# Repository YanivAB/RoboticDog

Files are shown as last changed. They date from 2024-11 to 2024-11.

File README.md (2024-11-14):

# Robotic Dog Project
This repository contains the code and resources for our final engineering project: a robotic dog designed and built as part of our Mechanical Engineering and Robotics studies at the Technion. The project integrates biomechanical principles to develop a four-legged robotic prototype that mimics the movements of a real dog.

# Project Overview
## Objective
The primary goal is to design and construct a robotic dog prototype capable of walking independently and transitioning between positions (stand, sit, and lie down). The project integrates:
Mechanical design and kinematics
Mechatronics and software development
Biomechanical concepts for robotic motion

## Key Features
Self-Stabilizing Movement: Robot walks and maintains balance on uneven terrain.
Pose Transitions: Switches between standing, sitting, and lying down positions.
Servo Motor System: Driven by SPT5425LV-W and MG996R servos, enabling precise control of leg joints.
Inverse Kinematics & Trajectory Planning: Ensures smooth movement through calculated joint angles.
Communication: Coordination between Raspberry Pi and Teensy microcontroller for motor control and trajectory planning.

# Hardware Components
Motors: SPT5425LV-W (25 kg/cm torque), MG996R (10 kg/cm torque)
Controller: Teensy microcontroller for PWM motor control
Processor: Raspberry Pi for kinematics calculations and trajectory planning
Structure: 3D-printed parts (PLA) for lightweight and robust assembly

# Software Architecture
Inverse Kinematics: IK(x, y) - Computes joint angles based on desired foot coordinates.
Trajectory Planning: trajectory_plan(x0, y0, R, steps) - Generates smooth movement paths for each leg.
Motor Control: send_angles(angles, pose_name) - Sends angle commands to each servo motor.

# Setup and Installation
## Prerequisites
Hardware: Raspberry Pi, Teensy, servo motors (SPT5425LV-W and MG996R)
Software: Python, Arduino IDE with required libraries for motor control (or custom PWM control)
Installation
Clone this repository:
bash
Copy code
git clone [https://github.com/username/robotic-dog-project.git]
cd robotic-dog-project
Load and compile the Teensy control code using the Arduino IDE.
Run the main Python scripts on the Raspberry Pi to initiate kinematics and control loops.

# Challenges and Solutions
Servo Durability: Reinforced motor gears with Teflon layers to improve durability under load.
Weight Distribution: Adjusted battery and motor placement for optimal balance.
Custom Movement Control: Developed custom code for efficient motor control and reduced reliance on pre-built libraries.

# Future Enhancements
Advanced Mobility: Additional gaits and obstacle avoidance
Remote Control via ROS: Integration with ROS for wireless operation
AI Capabilities: Vision processing and autonomous navigation

## Technion- Israel Institute of Technology

# Contributors
Natay Baruchis - https://www.linkedin.com/in/nitai-bruchis/
Yaniv Abramov - https://www.linkedin.com/in/yaniv-abramov/
Supervised by: Roman Shamsutdinov

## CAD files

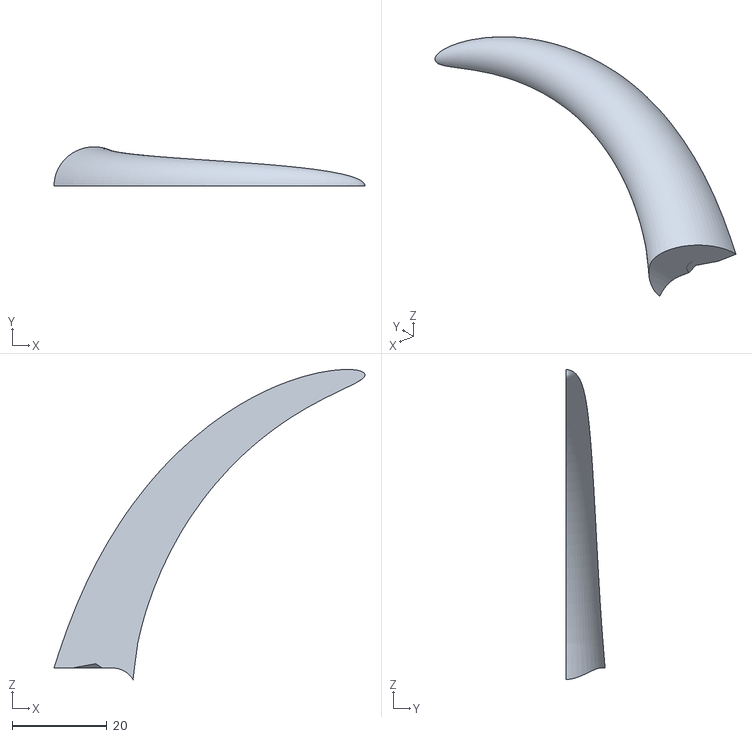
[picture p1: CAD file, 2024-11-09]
CAD_models/tail right.STL
65.7 x 8.30 x 65.5

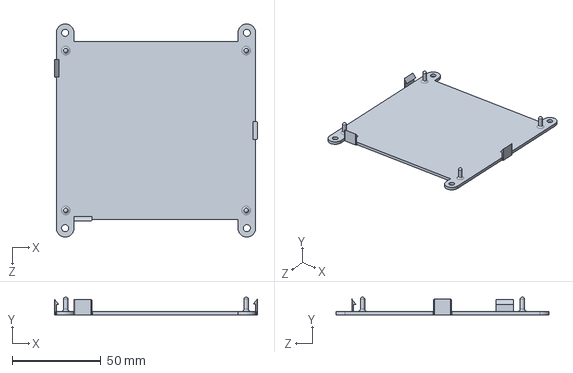
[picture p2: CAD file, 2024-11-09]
CAD_models/card caseing.SLDPRT
114.3 x 10.0 x 120.0 mm

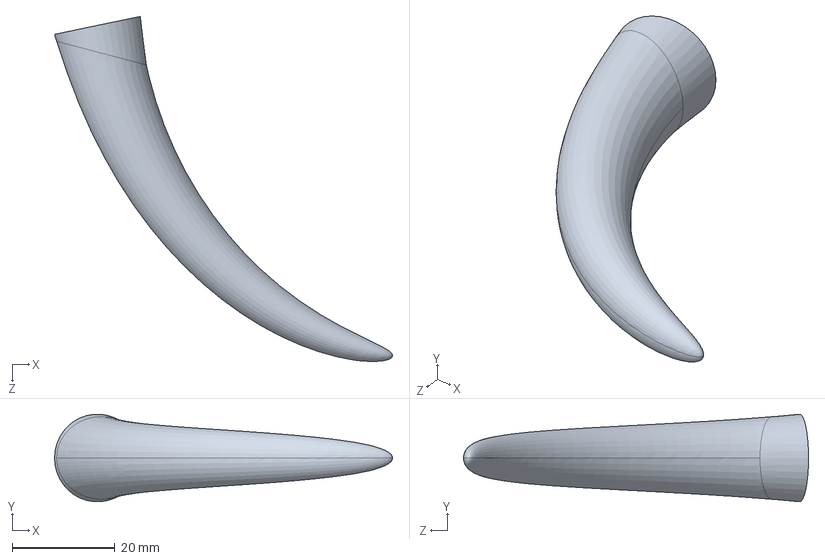
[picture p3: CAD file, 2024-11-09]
CAD_models/robot tail.SLDPRT
65.9 x 17.0 x 67.3 mm

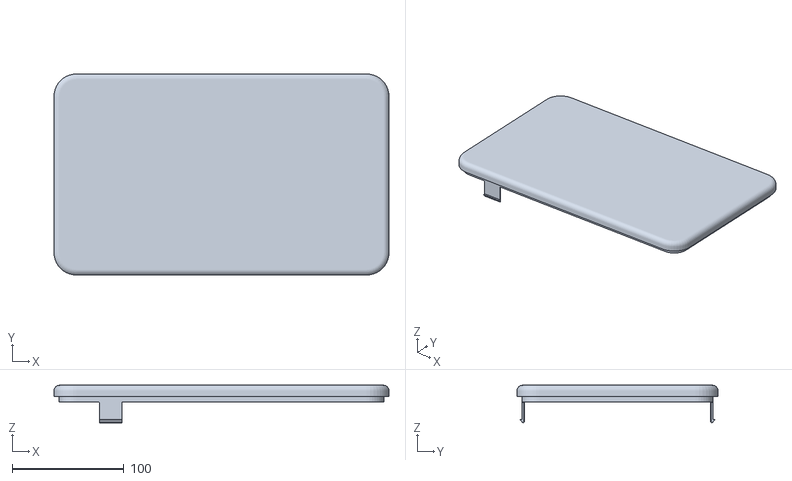
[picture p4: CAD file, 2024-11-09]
CAD_models/robot lid.STL
300.0 x 180.0 x 33.6

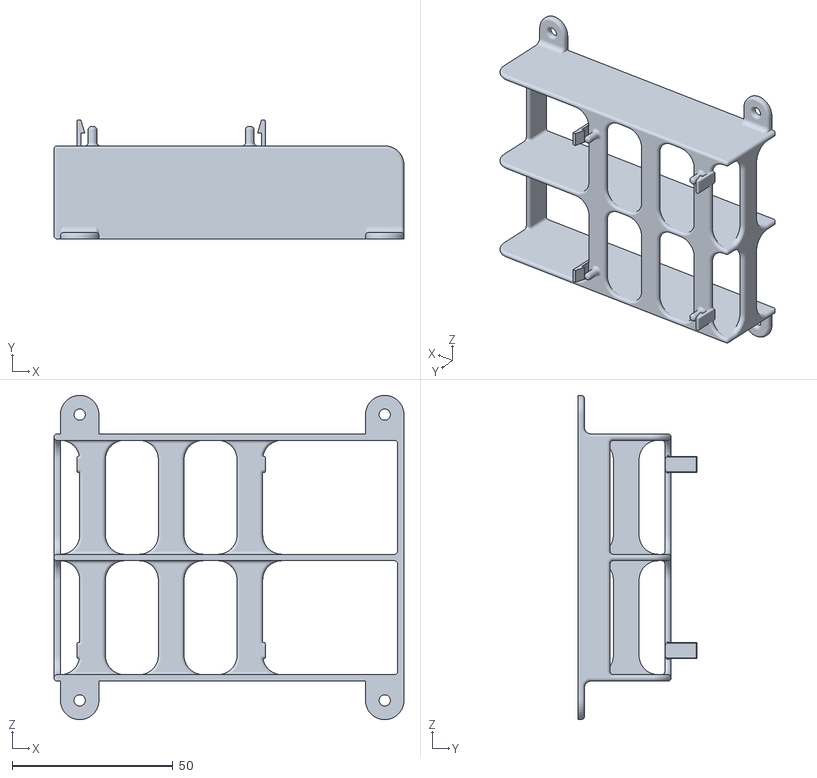
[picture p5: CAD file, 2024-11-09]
CAD_models/battery_casing2.STL
109.0 x 37.0 x 101.0

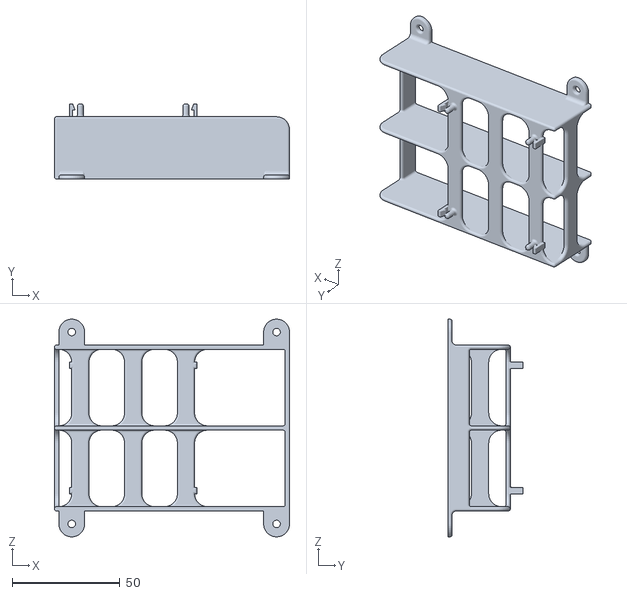
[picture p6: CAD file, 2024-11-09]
CAD_models/battery_casing1.STL
109.0 x 35.0 x 101.0

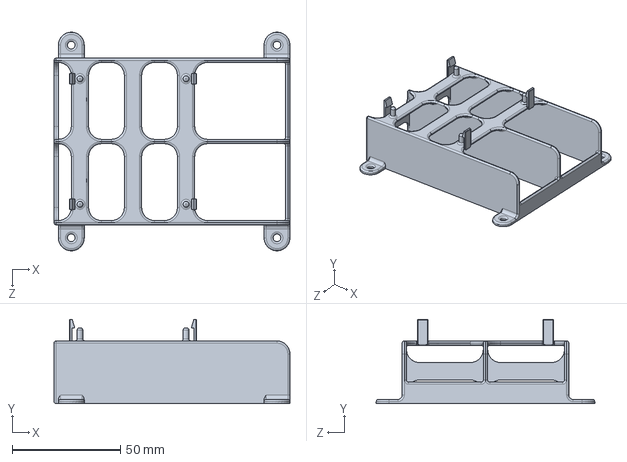
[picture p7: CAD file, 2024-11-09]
CAD_models/battery_casing.SLDPRT
109.0 x 39.0 x 101.0 mm

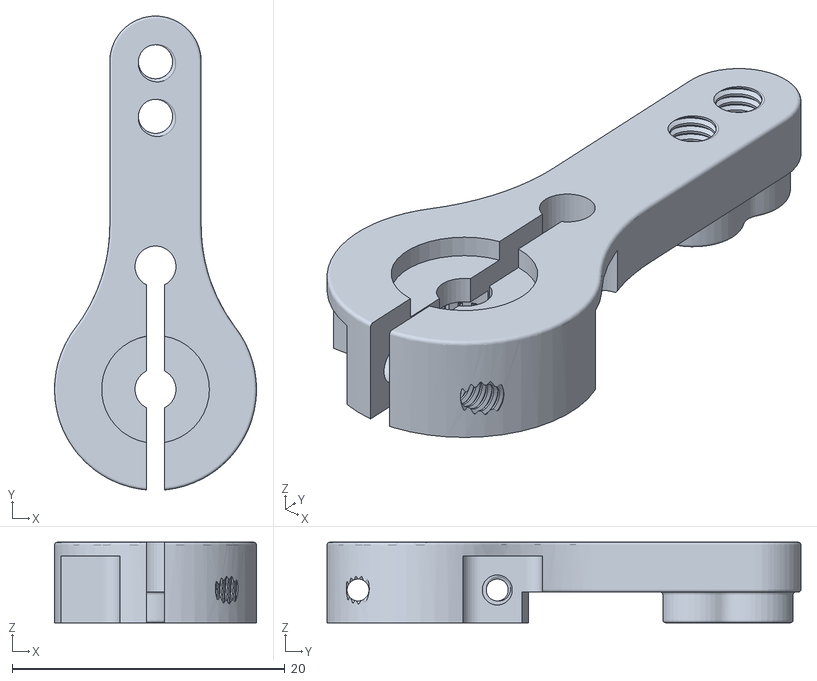
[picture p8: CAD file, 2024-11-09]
CAD_models/SERVO ARM HORN 25T ALUMINIUM.STL
14.8 x 34.7 x 5.90

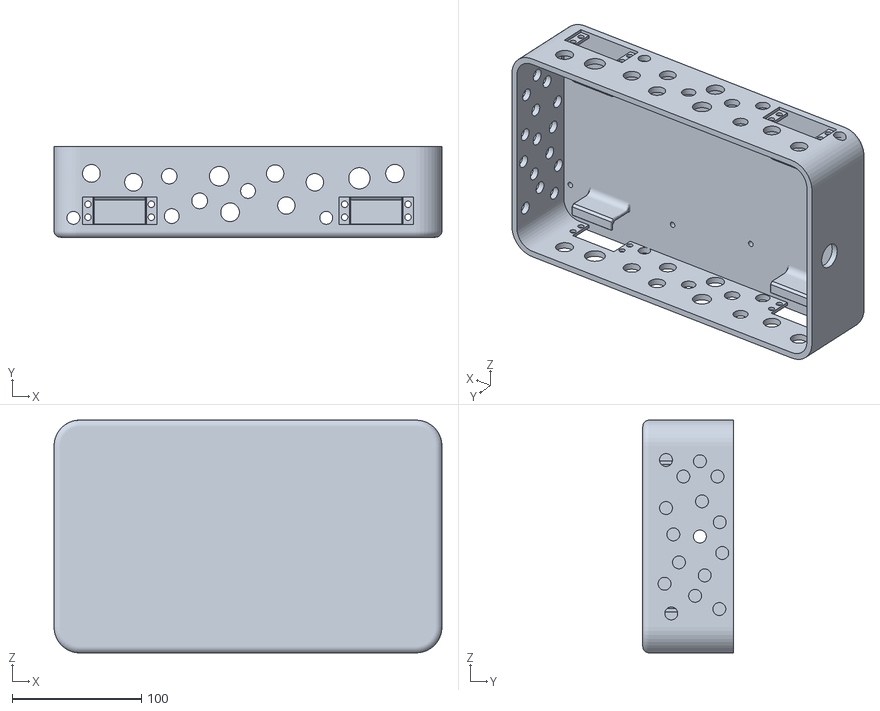
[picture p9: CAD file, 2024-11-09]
CAD_models/Torso_1.STL
300.0 x 70.0 x 180.0

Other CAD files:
CAD_models/tail left.STL
CAD_models/battery_casing.STL
CAD_models/card caseing.STL

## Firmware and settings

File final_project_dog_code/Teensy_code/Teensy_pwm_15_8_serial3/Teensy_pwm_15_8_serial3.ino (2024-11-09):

#include <Arduino.h>

#define ARM_MATH_CM4
#include <arm_math.h>
#define HWSERIAL Serial3  // UART

#define PWM_RSF 2  // PWM shoulder right front
#define PWM_REF 3  // PWM elbow right front
#define PWM_RSB 4  // PWM shoulder right back
#define PWM_REB 5  // PWM elbow right back
#define PWM_LSF 6  // PWM shoulder left front
#define PWM_LEF 7  // PWM elbow left front
#define PWM_LSB 8  // PWM shoulder left back
#define PWM_LEB 9  // PWM elbow left back

char greeting = 1;  // The program welcomes
char control = 0;   // 1 begin control loop

const int down[8] = {10 /*RSF*/, 70, 10, 70, 165 /*LSF*/, 170, 165, 170};


/*
int p1 = 1600, new_angle1 = 0, old_angle1 = 0, e1 = 0;
int p2 = 1600, new_angle2 = 0, old_angle2 = 0, e2 = 0;
int p3 = 1600, new_angle3 = 0, old_angle3 = 0, e3 = 0;
int p4 = 1600, new_angle4 = 0, old_angle4 = 0, e4 = 0;
int p5 = 1600, new_angle5 = 0, old_angle5 = 0, e5 = 0;
int p6 = 1600, new_angle6 = 0, old_angle6 = 0, e6 = 0;
int p7 = 1600, new_angle7 = 0, old_angle7 = 0, e7 = 0;
int p8 = 1600, new_angle8 = 0, old_angle8 = 0, e8 = 0;
*/

//down
int p1 = 1970, new_angle1 = 0, old_angle1 = 10, e1 = 0;
int p2 = 4190, new_angle2 = 0, old_angle2 = 70, e2 = 0;
int p3 = 1970, new_angle3 = 0, old_angle3 = 10, e3 = 0;
int p4 = 4190, new_angle4 = 0, old_angle4 = 70, e4 = 0;
int p5 = 7705, new_angle5 = 0, old_angle5 = 165, e5 = 0;
int p6 = 7830, new_angle6 = 0, old_angle6 = 145, e6 = 0;
int p7 = 7705, new_angle7 = 0, old_angle7 = 165, e7 = 0;
int p8 = 7830, new_angle8 = 0, old_angle8 = 180, e8 = 0;


int pmin = 1600;
int pmax = 8200;

/*   UART setup              */
unsigned char bytecount = 0;
unsigned char received_data[0x08] = { 0 };
unsigned char p = 0;
unsigned char i = 0;


volatile bool ledState = false;  // from ChatGPT

void setup() {
  // from ChatGPT begin
  pinMode(LED_BUILTIN, OUTPUT);

  // Stop the timers before configuration
  PIT_MCR = 0x00;  // Enable PIT and disable freezing in the debugger

  // PIT0 configuration
  PIT_LDVAL0 = 200000 - 1;  // Set timer period (1 second at 120 MHz)
  PIT_TCTRL0 = 0x3;         // Enable timer and interrupt

  // Assign interrupt function
  attachInterruptVector(IRQ_PIT, pit0_isr);
  NVIC_ENABLE_IRQ(IRQ_PIT);
  // end ChatGPT


// UART
Serial3.begin(115200);
Serial.begin(115200);

// PWM Setup
analogWriteResolution(16);  // analogWrite value 0 to 4095, or 4096 for high
// analogWriteResolution(10);  // analogWrite value 0 to 1023, or 1023 for high

// sample  analogWriteFrequency(2, 10000);   // PWM frequency 10kHZ
analogWriteFrequency(2, 50);  // PWM frequency 50 HZ
analogWriteFrequency(3, 50);  // PWM frequency 50 HZ
analogWriteFrequency(4, 50);  // PWM frequency 50 HZ
analogWriteFrequency(5, 50);  // PWM frequency 50 HZ
analogWriteFrequency(6, 50);  // PWM frequency 50 HZ
analogWriteFrequency(7, 50);  // PWM frequency 50 HZ
analogWriteFrequency(8, 50);  // PWM frequency 50 HZ
analogWriteFrequency(9, 50);  // PWM frequency 50 HZ

/* PinMode setup */

  pinMode(PWM_RSF, OUTPUT);
  pinMode(PWM_REF, OUTPUT);
  pinMode(PWM_RSB, OUTPUT);
  pinMode(PWM_REB, OUTPUT);
  pinMode(PWM_LSF, OUTPUT);
  pinMode(PWM_LEF, OUTPUT);
  pinMode(PWM_LSB, OUTPUT);
  pinMode(PWM_LEB, OUTPUT);


// test
//  analogWrite(PWM_RSF, 3300); = 1.007ms
// analogWrite(PWM_RSF, 2950);  // 900ms
// analogWrite(PWM_REB, 6900);  // 2100ms
//  analogWrite(PWM_RSF, 1600); //8200
//  analogWrite(PWM_REF, 4950);
//  analogWrite(PWM_RSB, 6050);
//  analogWrite(PWM_REB, 6900);  // 2100ms

}

void loop() 
{
  // Main loop is empty, all work is done in the interrupt
// The program welcomes
if (greeting == 1) {
  Serial.println("Teensy 4.0 RS motors control v000 ");
  


analogWrite(PWM_RSF, p1);
analogWrite(PWM_REF, p2);
analogWrite(PWM_RSB, p3);
analogWrite(PWM_REB, p4);


analogWrite(PWM_LSF, p5);
analogWrite(PWM_LEF, p6);
analogWrite(PWM_LSB, p7);
analogWrite(PWM_LEB, p8);    

  greeting = 0;
}

/* read data from UART */
while (Serial3.available() && bytecount < 0x08) {
  received_data[bytecount] = Serial3.read();
  Serial.println(received_data[bytecount], HEX);
  bytecount++;
}

if (bytecount == 0x08) {

  new_angle1 = received_data[0x00];
  new_angle2 = received_data[0x01];
  new_angle3 = received_data[0x02];
  new_angle4 = received_data[0x03];
  new_angle5 = received_data[0x04];
  new_angle6 = received_data[0x05];
  new_angle7 = received_data[0x06];
  new_angle8 = received_data[0x07];

/*
  pnew1 = pmin + (received_data[0x00] * 37);
  pnew2 = pmin + (received_data[0x01] * 37);
  pnew3 = pmin + (received_data[0x02] * 37);
  pnew4 = pmin + (received_data[0x04] * 37);
  pnew6 = pmin + (received_data[0x05] * 37);
  pnew7 = pmin + (received_data[0x06] * 37);
  pnew8 = pmin + (received_data[0x07] * 37);
*/
  p = 1;
  bytecount = 0;
  control = 1;
}

if (p == 1) {
  for (i = 0; i < 0x08; i++) {
    //Serial.println(received_data[i], HEX);  // number, base 16/hexadecimal
    //Serial.println(p1, DEC);                // number, base 16/hexadecimal
  }

  // Serial1.print("M_En = ");
  // Serial.println(motors, DEC);  // number, base 16/hexadecimal
  p = 0;
}
}



void pit0_isr() 
{
    if (PIT_TFLG0 & 1)   // Check the interrupt flag for PIT0
    {  

      if(control == 1) 
      {
// Control loop for RC motor 1
if (old_angle1 != new_angle1) {
  e1 = old_angle1 - new_angle1;
  if (e1 < 0) {
    old_angle1 = old_angle1 + 1;
  } else {
    old_angle1 = old_angle1 - 1;
  }
  p1 = pmin + (old_angle1 * 37);
  analogWrite(PWM_RSF, p1);
} else {
  old_angle1 = new_angle1;
}

// Control loop for RC motor 2
if (old_angle2 != new_angle2) {
  e2 = old_angle2 - new_angle2;
  if (e2 < 0) {
    old_angle2 = old_angle2 + 1;
  } else {
    old_angle2 = old_angle2 - 1;
  }
  p2 = pmin + (old_angle2 * 37);
  analogWrite(PWM_REF, p2);
} else {
  old_angle2 = new_angle2;
}

// Control loop for RC motor 3
if (old_angle3 != new_angle3) {
  e3 = old_angle3 - new_angle3;
  if (e3 < 0) {
    old_angle3 = old_angle3 + 1;
  } else {
    old_angle3 = old_angle3 - 1;
  }
  p3 = pmin + (old_angle3 * 37);
  analogWrite(PWM_RSB, p3);
} else {
  old_angle3 = new_angle3;
}

// Control loop for RC motor 4
if (old_angle4 != new_angle4) {
  e4 = old_angle4 - new_angle4;
  if (e4 < 0) {
    old_angle4 = old_angle4 + 1;
  } else {
    old_angle4 = old_angle4 - 1;
  }
  p4 = pmin + (old_angle4 * 37);
  analogWrite(PWM_REB, p4);
} else {
  old_angle4 = new_angle4;
}

// Control loop for RC motor 5
if (old_angle5 != new_angle5) {
  e5 = old_angle5 - new_angle5;
  if (e5 < 0) {
    old_angle5 = old_angle5 + 1;
  } else {
    old_angle5 = old_angle5 - 1;
  }
  p5 = pmin + (old_angle5 * 37);
  analogWrite(PWM_LSF, p5);
} else {
  old_angle5 = new_angle5;
}

// Control loop for RC motor 6
if (old_angle6 != new_angle6) {
  e6 = old_angle6 - new_angle6;
  if (e6 < 0) {
    old_angle6 = old_angle6 + 1;
  } else {
    old_angle6 = old_angle6 - 1;
  }
  p6 = pmin + (old_angle6 * 37);
  analogWrite(PWM_LEF, p6);
} else {
  old_angle6 = new_angle6;
}

// Control loop for RC motor 7
if (old_angle7 != new_angle7) {
  e7 = old_angle7 - new_angle7;
  if (e7 < 0) {
    old_angle7 = old_angle7 + 1;
  } else {
    old_angle7 = old_angle7 - 1;
  }
  p7 = pmin + (old_angle7 * 37);
  analogWrite(PWM_LSB, p7);
} else {
  old_angle7 = new_angle7;
}

// Control loop for RC motor 8
if (old_angle8 != new_angle8) {
  e8 = old_angle8 - new_angle8;
  if (e8 < 0) {
    old_angle8 = old_angle8 + 1;
  } else {
    old_angle8 = old_angle8 - 1;
  }
  p8 = pmin + (old_angle8 * 37);
   analogWrite(PWM_LEB, p8);
} else {
  old_angle8 = new_angle8;
}

/*     
analogWrite(PWM_RSF, p1);
analogWrite(PWM_REF, p2);
analogWrite(PWM_RSB, p3);
analogWrite(PWM_REB, p4);
analogWrite(PWM_LSF, p5);
analogWrite(PWM_LEF, p6);
analogWrite(PWM_LSB, p7);
analogWrite(PWM_LEB, p8);
*/

    }

        PIT_TFLG0 = 1;         // Clear the interrupt flag
        ledState = !ledState;  // Toggle the LED state
        digitalWrite(LED_BUILTIN, ledState);
    }
}

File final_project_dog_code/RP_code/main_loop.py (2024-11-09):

import math
import serial
import time
import RPi.GPIO as GPIO
import pickle
import os

from IK_func_8 import IK, RSF , RSB , REF , REB , LSF , LEB , LEF , LEB , theta2servo , trajectory_plan , traj_use , turn_angles

def ledon(ledpin):
    GPIO.setmode(GPIO.BCM)
    GPIO.setup(ledpin , GPIO.OUT)
    GPIO.output(ledpin , GPIO.HIGH)
    time.sleep(2)
    GPIO.output(ledpin , GPIO.LOW)
print('initializing')
# Setup serial communication and transmission function
ser = serial.Serial('/dev/ttyAMA0',115200, timeout=1)
t_delay_poses = 1.5
def send_angles(angles, pose_name, slp = t_delay_poses):
    print(pose_name)
    if len(angles) != 8:
        print('error')
        return
    hex_array = bytearray(angles)
    ser.write(hex_array)
    time.sleep(slp)
    print('done ' ,angles , pose_name)

def load_data(filename):
    """
    Loads data from a pickle file.
    
    Args:
    filename (str): The name of the file to load the data from.

    Returns:
    data (any): The loaded data.
    """
    with open(filename, 'rb') as f:
        return pickle.load(f)

# def executing function for steps
def step_act(step_angles, N , delay):
    send_angles(stand , 'stand')
    for n in range(N):
        print(f"iteration {n}")
        for m in range(len(step_angles)):
            send_angles(step_angles[m] , f"point {m}" , t_delay_step)
    send_angles(stand , 'stand')

def turn(turn_angles, N, delay ):	
    send_angles(stand , 'stand')
    n_angles = len(turn_angles)
    for n in range(N):
        #print(f"iteration {n}")
        for m in range(n_angles):
            send_angles(turn_angles[m] + stand[2:-1] , f"point {m}" , t_delay_step)
    send_angles(stand , 'stand')


# Set basic positions
theta1_stand , theta2_stand = 50 , 125
theta1_down , theta2_down = 10 , 70

down_showoff = [10 , 70 , 10 , 70 , 165 , 170 , 165 , 170]    
stand_showoff = [50, 160, 50, 160, 125, 80, 125, 80]  # motor 6 is not synced to motor 8's zero point because of mechanical damage
sit_showoff = [50 , 160 , 10 , 70 , 125 , 80 , 165 , 170]
zeros = [0,90,0,70,175,150,175,170]
down = theta2servo(theta1_down , theta2_down ,theta1_down , theta2_down, theta1_down , theta2_down, theta1_down , theta2_down)
stand = theta2servo(theta1_stand , theta2_stand ,theta1_stand , theta2_stand, theta1_stand , theta2_stand, theta1_stand , theta2_stand)
sit = theta2servo(theta1_stand , theta2_stand ,theta1_down , theta2_down, theta1_stand , theta2_stand, theta1_down , theta2_down)
print('calculating Inverse Kinematics and Trajectory')
# Setup trajectory parameters
#x0 , y0 = -20 , 180  # coordinates for the starting point of the leg
#R = 20 # radius of step's circle
#steps = 10 # number of iterations for a step
#N_steps = 5  # number of whole steps
#t_delay_step = 0.2


''' working sets:
slowmotion fot showing the consept: R , steps , N_steps , t_delay_steps = 25 , 20 , 5 , 0.2
best motion: R , steps , N_steps , t_delay_steps = 20 , 10 , 5 , 0.2
'''


# set up main loop
# Set up GPIO mode
GPIO.setmode(GPIO.BCM)
GPIO.setwarnings(False)
sw_pin = 4
# Set up GPIO 17 as an input with pull-down resistor
GPIO.setup(sw_pin, GPIO.IN, GPIO.PUD_DOWN)
# get the trajectory data
#x_trj , y_trj , len_arc = trajectory_plan(x0 , y0 , R , steps)

print('waiting for switch changing')
switch_on = False
while not switch_on:
	ledon(26)
	button_state = GPIO.input(sw_pin)
	if button_state == GPIO.HIGH:
		print(type(button_state), GPIO.HIGH)
		print('high')
		switch_on = True
	else:
		print(button_state)
		print('low')
	time.sleep(0.5)

# show poses
send_angles(down_showoff, 'down')
send_angles(stand_showoff , 'stand')
send_angles(sit_showoff, 'sit')
send_angles(down_showoff, 'down')
send_angles(sit_showoff, 'sit')
send_angles(stand_showoff, 'stand')
#send_angles(zeros, 'zero')

os.chdir('/usr/local/bin')
step_ang_mat = load_data("step_angles.pkl")
R_turn, L_turn = load_data("turn_angles.pkl")
walk_back= load_data("walkback_angles.pkl")

ledon(26)

# step action
N_steps = 5  # number of whole steps
t_delay_step = 0.2
send_angles(stand, 'stand')
step_act(step_ang_mat, N_steps , t_delay_step)

#turn right
N_turn_iter = 4

step_act(R_turn, N_turn_iter, t_delay_step*2)
#turn left
#step_act(L_turn, N_turn_iter , t_delay_step*2)

step_act(step_ang_mat, N_steps , t_delay_step)
step_act(walk_back, N_steps , t_delay_step)


#end showoff
send_angles(stand_showoff , 'stand',t_delay_poses*2)
send_angles(sit_showoff, 'sit',t_delay_poses*2)
send_angles(down_showoff, 'down',t_delay_poses*2)
